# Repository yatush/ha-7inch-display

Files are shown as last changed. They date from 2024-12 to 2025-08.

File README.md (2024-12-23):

ha-7inch-display
================
**Wall mounted 7 inch touch display for HA, based on OrangePi Zero 3, with motion detector.**

# Background
A project to create a HA display to mount on walls. Featuring:
* 7 inch touch display.
* Fully functional unix working running on [OrangePi Zero 3](http://www.orangepi.org/html/hardWare/computerAndMicrocontrollers/details/Orange-Pi-Zero-3.html).
* Power supply and OrangePi fits into outlet box (deep version of it).
* Motion sensor to wake up on pre-defined distance movement.

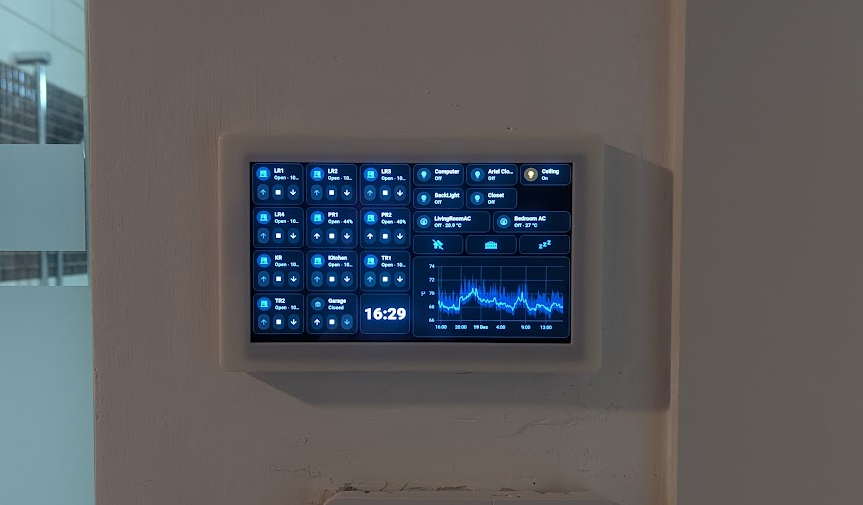
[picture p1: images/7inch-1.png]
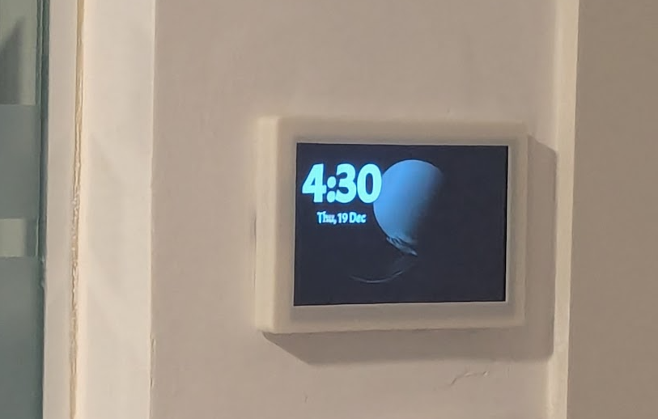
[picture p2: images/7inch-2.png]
 

# Hardware

## Touch screen - 7 Inch Touch Screen IPS 1024x600 HD LCD HDMI-compatible

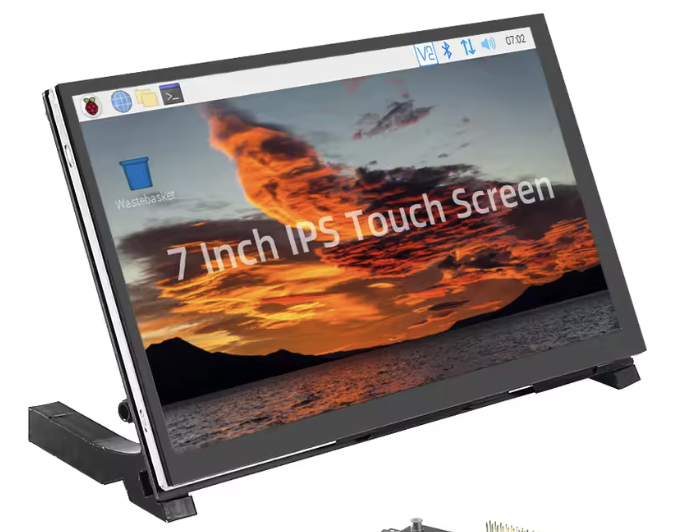
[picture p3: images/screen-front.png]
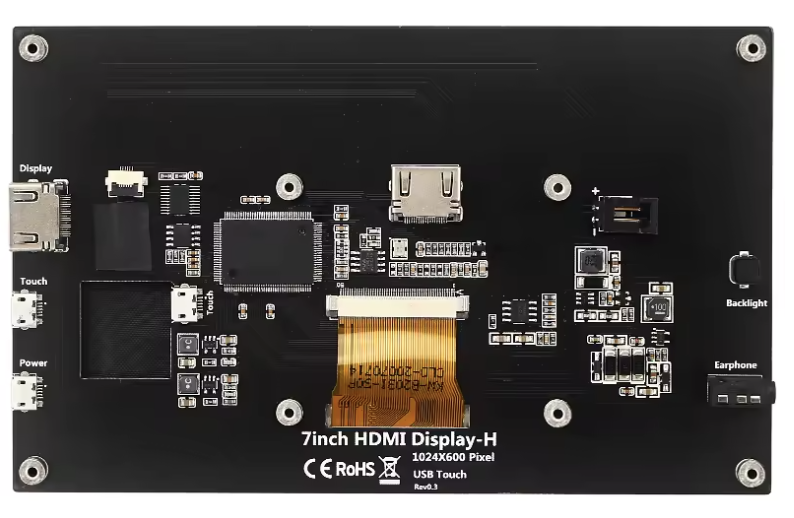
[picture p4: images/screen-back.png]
 

* 1024x600 IPS resolution
* [Aliexpress link](https://www.aliexpress.com/item/1005001485174459.html)
* Please make sure you choose the one with the back looking like this - HDMI connector and four round "legs" on the corners.
* Price: ~36 USD.

## Power supply - AC-DC to DC Step-Down Power Supply Module AC85-220V to DC 5V 2A



* 110V/220V -> 5V2A converter that fits in the wall box.
* [Aliexpress link](https://www.aliexpress.com/item/1005005142108650.html)
* Price: ~6 USD.

## SBC - Orange pi zero 3 (2GB Ram version)

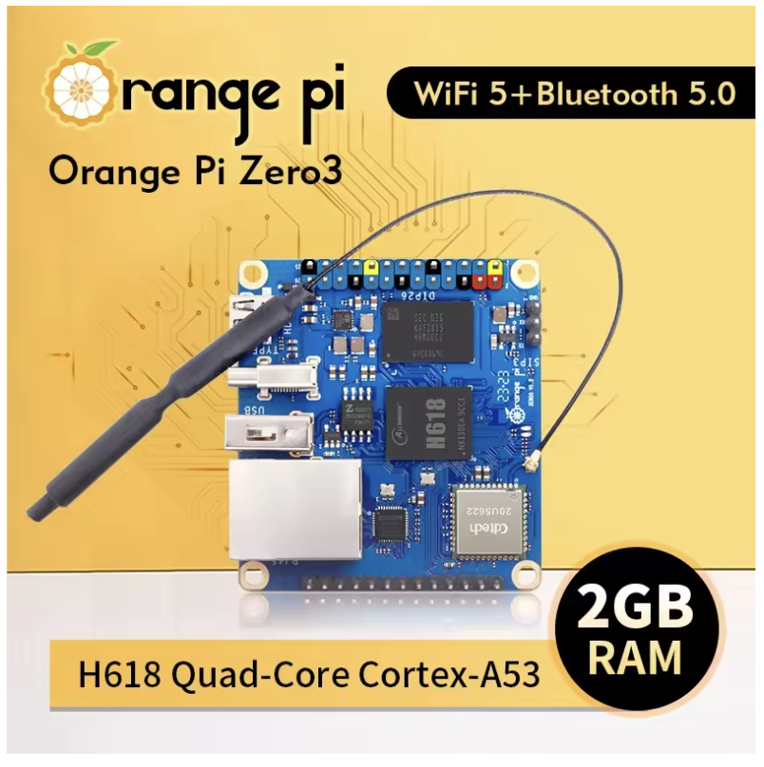
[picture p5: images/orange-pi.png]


* Small factor SBC
* I've tried running this with Raspberry pi 4 - it's both more expensive, heats up more, and needs more power.  The Orange Pi Zero 3 is perfect for this usage.
* [Aliexpress link](https://www.aliexpress.com/item/1005006170910291.html)
* Price: ~26 USD.

## Passive cooling case for the Orange Pi

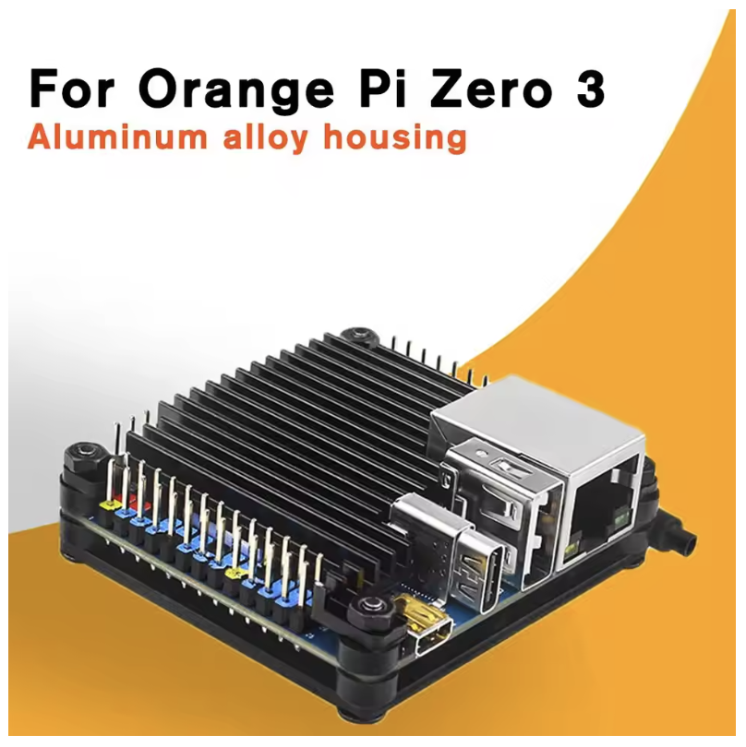
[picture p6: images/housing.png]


* Also protects from physical damage.
* [Aliexpress link](https://www.aliexpress.com/item/1005005886279442.html)
* Price: ~4 USD

## SD card for the SBC

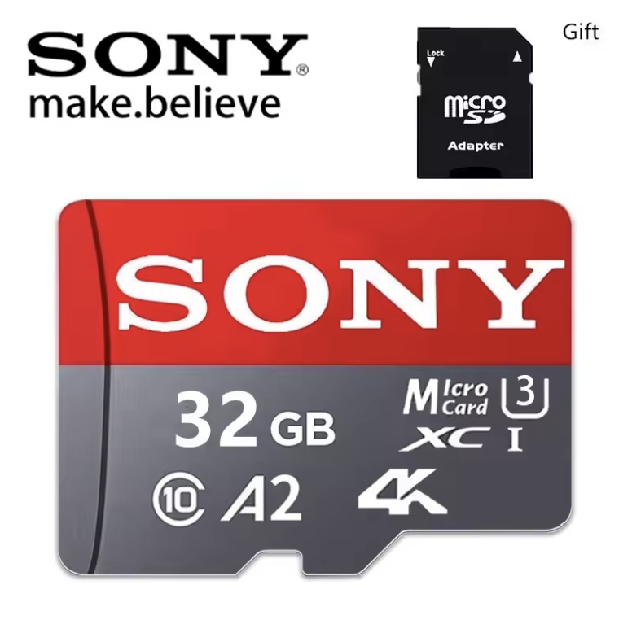
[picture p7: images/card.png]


* Any 32 GB micro SD card will do the work.
* [Aliexpress link](https://www.aliexpress.com/item/1005007897862434.html)
* An SDCard reader is also needed, to burn the image to the SD Card.
* Price: ~3 USD.

## HDMI cable to connect the Orange Pi to the screen

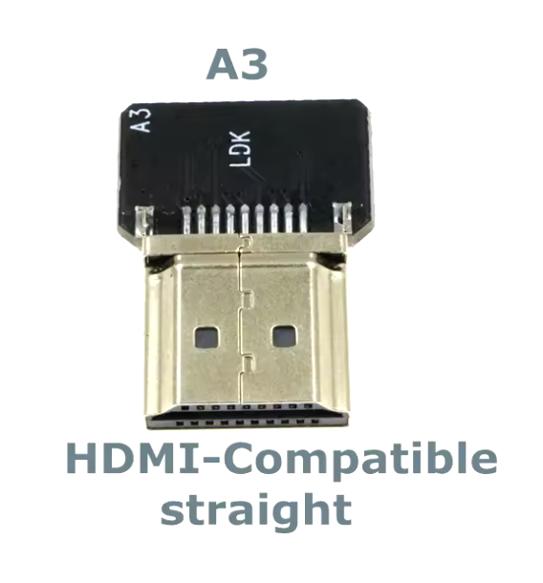
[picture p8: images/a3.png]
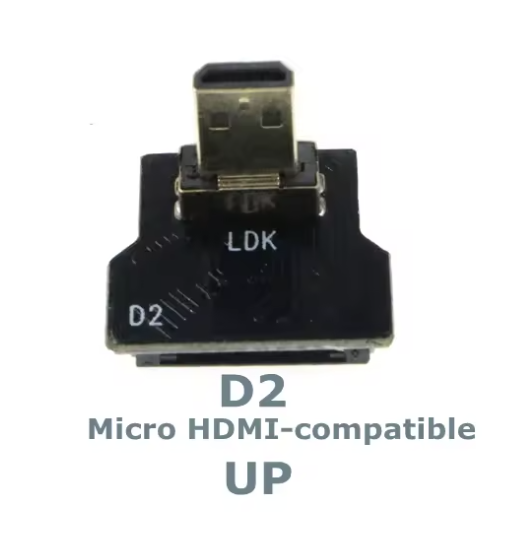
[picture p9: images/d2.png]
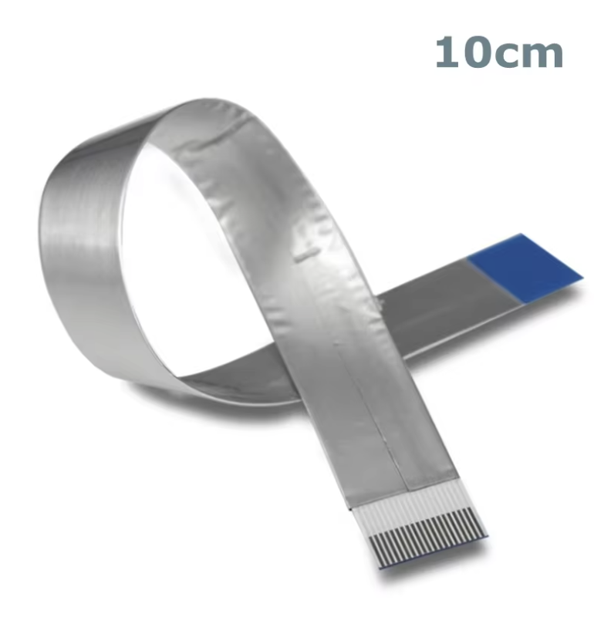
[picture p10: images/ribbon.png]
  

* Built out of three parts - two connectors and the ribbon:
  * The first connector - model A3.
  * The second connector - model D2.
  * the connecting ribbon - length of 10 c"m.
* [Aliexpress link](https://www.aliexpress.com/item/1005006426262787.html) (choose the three parts separately).
* Price: ~7 USD for all three parts.

## USB cable to connect the Orange Pi to the screen

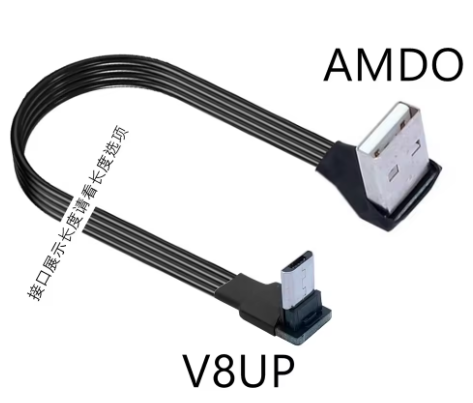
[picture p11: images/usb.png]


* Pay attention to the connectors (AMDO V8UP)
* Length of 10cm.
* [Aliexpress link](https://www.aliexpress.com/item/1005005979020420.html)
* Price: ~5 USD.

## USB-C Power plug

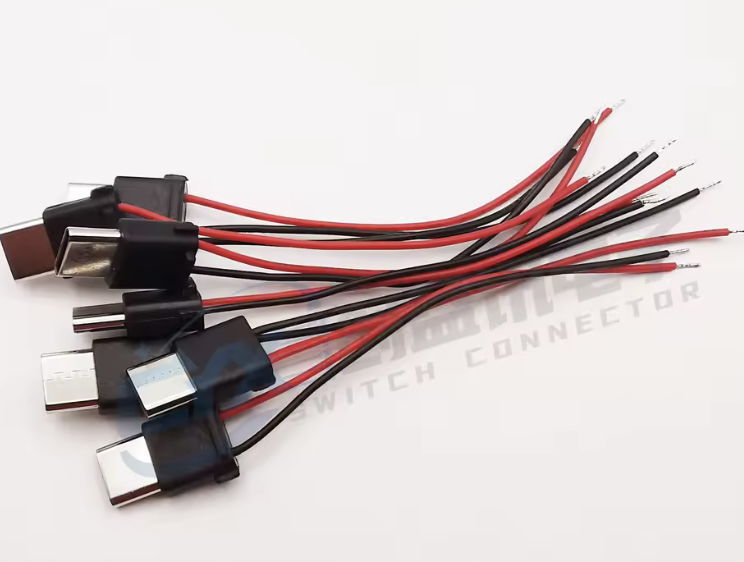
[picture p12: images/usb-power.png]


* Any other compact USB-C plug should do the work.
* [Aliexpress link](https://www.aliexpress.com/item/1005005419728912.html)
* Price: ~3 USD (for a pack of 10, only 1 is needed)

## Motion sensor - LD2410b

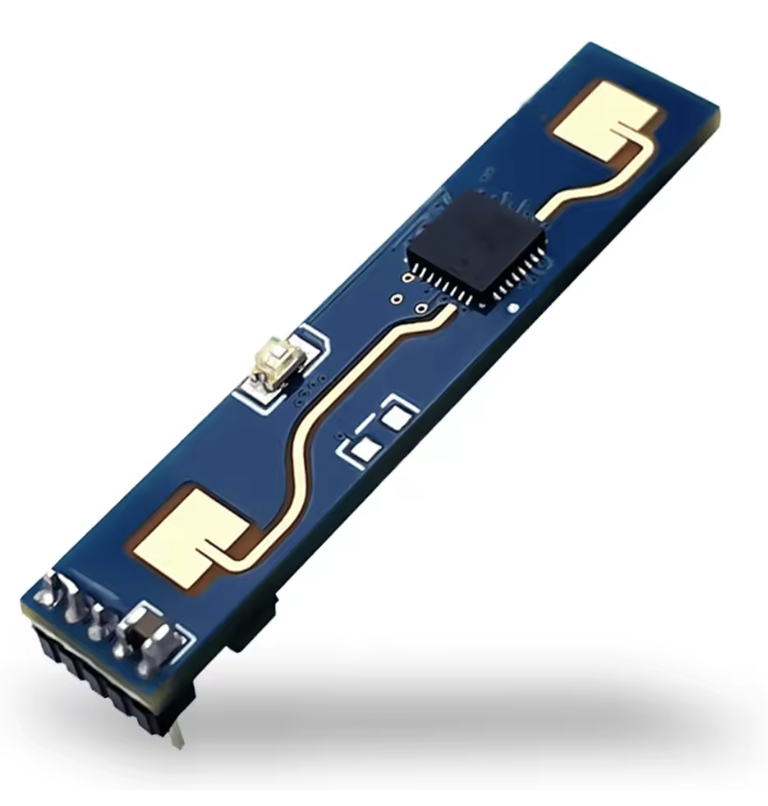
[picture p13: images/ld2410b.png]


* Choose a model where there are welded pins.
* [Aliexpress link](https://www.aliexpress.com/item/1005005242873516.html)
* Price: ~3 USD

## Motion sensor cable

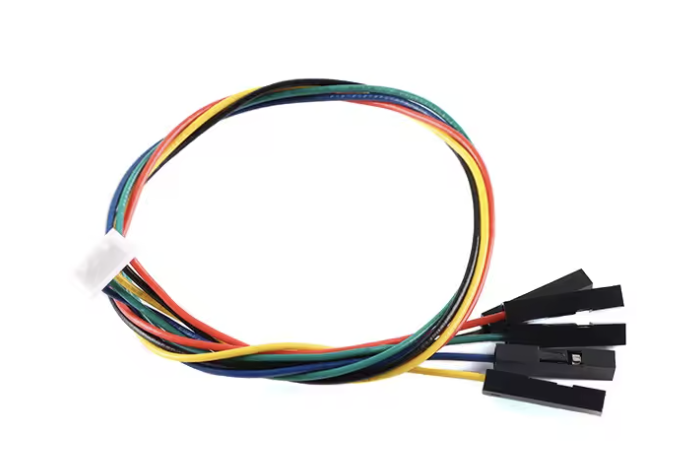
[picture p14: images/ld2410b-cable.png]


* [Aliexpress link](https://www.aliexpress.com/item/1005007055937689.html)
* Price: ~1 USD

## Outlet box

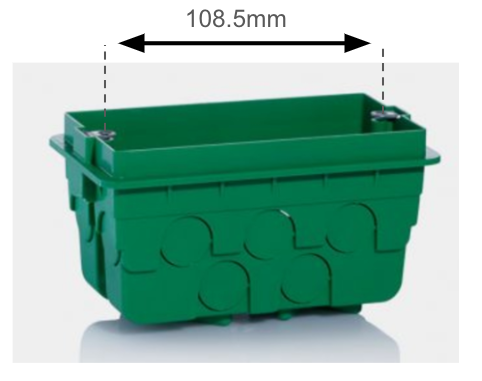
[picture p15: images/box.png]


* This is the outlet box I'm using.
* Important measurements:
  * Length: 121mm
  * Width: 67mm
  * Depth: 74mm
  * Distance between screws: 108.5mm
* For other between-screws-distance the 3d model should be modified, this should not be a problem.
* I think this is the minimum size for the outlet box, otherwise, all the electronics will not fit in.

## (Optional) Keyboard to control the display

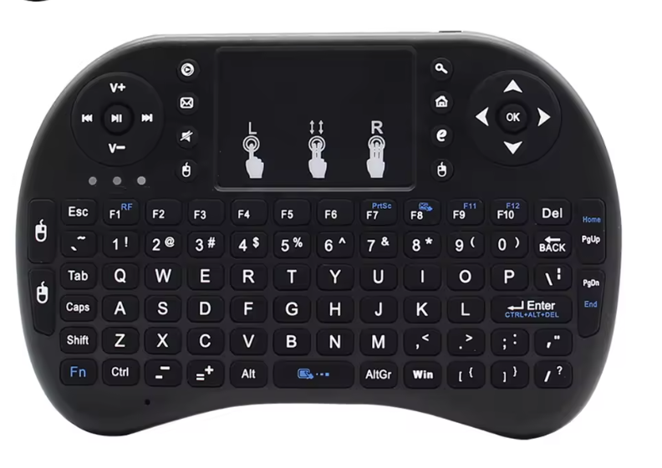
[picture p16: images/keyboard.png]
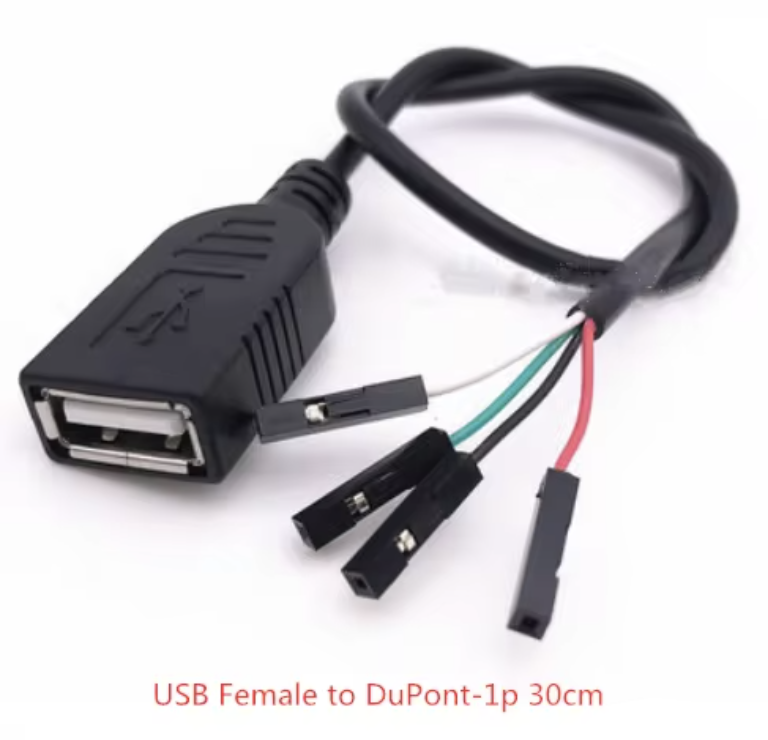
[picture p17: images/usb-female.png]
 

* There's no need while the system is "running" to control it via keyboard.
* However, for initial setup, and in case things go wrong for some reason, this is really convenient.
* Because OPI03 has only one usb pory (used for the screen), we need to also add a pin-connected USB port.
* [Aliexpress link - keyboard](https://www.aliexpress.com/item/1005004085232177.html)
* [Aliexpress link - USB port](https://www.aliexpress.com/item/1005004492194988.html)
* Price: ~4 USD + ~3 USD = ~7 USD.

# On the wall wiring diagram

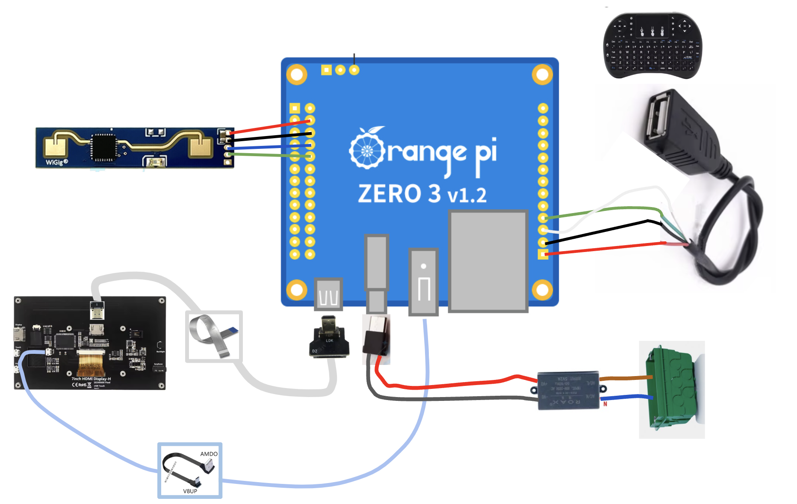
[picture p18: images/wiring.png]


* ***IMPORTANT:*** There's a power input connector in the back of the screen, it has to be removed - just pull the black plastic.

# Installation process

## Download and burn the Orange Pi OS(Arch) to the micro SD card
* Download the Debian Bookworm desktop image from [this](http://www.orangepi.org/html/hardWare/computerAndMicrocontrollers/service-and-support/Orange-Pi-Zero-3.html) site.
* Burn it to an micro SD card, following the instructions [here](http://www.orangepi.org/orangepiwiki/index.php/Orange_Pi_Zero_3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).

## Initial startup
* Connect according to the wiring diagram
* Once the linux image is up, connect to the internet (using the icon on the top left part of the screen).

## Add scripts content
* Add the content of /scripts/kiosk.sh to ```/home/orangepi/kiosk.sh```
* Add the content of /scripts/ld2410.py to ```/home/orangepi/ld2410.py```
* Change the variable values defined in the top part of ```kiosk.sh```.
* Make sure the two files are executable:
```
chmod 777 /home/orangepi/kiosk.sh
chmod 777 /home/orangepi/ld2410.py
```

## Install required components
Run all the following:
```
sudo apt-get install pip
```
```
sudo pip3 install keyboard --break-system-packages
```
```
sudo pip3 install git+https://github.com/vjsyong/LD2410.git --break-system-packages
```
```
sudo pip3 install requests --break-system-packages
```
```
sudo pip3 install pySerial --break-system-packages
```
```
sudo apt-get install unclutter-xfixes
```

## Set ```kiosk.sh``` to start on startup
* From the top right menu: Applications->Settings->Session and Startup -> Application and Autostart -> add ```/home/orangepi/kiosk.sh```

## Set timezone:
* See available timezones by:
```
timedatectl list-timezones
```
* Choose the right one and set it to the system by:
```
timedatectl set-timezone XXXX
```

## Remove sudo passwords for orangepi user
* Open a Terminal window and type:
```
sudo visudo
```
* In the bottom of the file, change to the following line:
```
orangepi ALL=(ALL) NOPASSWD: ALL
```

## Enable the UART5 for radar
* From the terminal, run
```
sudo orangepi-config
```
* System -> Hardware
* Go down to ```ph-uart5``` press space to toggle
* Save -> Back -> Reboot.

**After following the above process, the system should restart and HA should start**

# Changes to HA
## WallPanel
* I'm using the (WallPanel)[https://github.com/j-a-n/lovelace-wallpanel] for "screensaver" options. The python scripts omits "alt" every time it senses a movement in less than 150c"m from it, which triggers the wall panel to get out of the screensaver.
* The WallPanel configuration I'm using (for reference):
```
wallpanel:
  cards:
    - type: custom:digital-clock
      firstLineFormat: h:mm
      card_mod:
        style: |
          ha-card {
            background-color: transparent;
            box-shadow: none;
            border: none;
            font-size: 5vw;
            color: #aaa;
            font-family: 'Acme', sans-serif;
            display: inline-block;
          }
          ha-card .first-line {
            font-size: 20vw;
          }
          ha-card .second-line {
            font-size: 5vw;
          }
  enabled: false
  debug: false
  hide_toolbar: true
  hide_sidebar: true
  fullscreen: false
  idle_time: 15
  image_url: /
  image_animation_ken_burns: false
  image_order: random
  show_images: true
  show_progress_bar: false
  display_time: 120
  keep_screen_on_time: 0
  black_screen_after_time: 0
  control_reactivation_time: 1
  screensaver_entity: input_boolean.wallpanel_screensaver
  info_animation_duration_x: 300
  info_animation_duration_y: 180
  info_animation_timing_function_x: steps(10, end)
  info_animation_timing_function_y: steps(6, end)
  info_move_pattern: random
  info_move_interval: 0
  info_move_fade_duration: 2
  card_interaction: false
  style:
    wallpanel-screensaver-image-overlay:
      background: rgba(0,0,0,0.6)
    wallpanel-screensaver-info-box-content:
      background: '#00000000'
    wallpanel-screensaver-info-box:
      '--wp-card-width': 45vw
```
* The step function in ```info_animation_timing_function_x/y``` is used to reduce the CPU usage.
* I use dark images (so that while the screen is in screensaver mode, it doesn't emit a lot of light). A sample of backgrounds are available under the ```backgrounds``` directory.
* Once this is all done, in the URL of starting the HA (in the ```kiosk.sh``` script), add:

  https://HA_URL/DASHBOARD/0<b>?wp_enabled=true</b>

  to start the WallPanel on startup.

## Other HA changes
* I'm using the dark mode of HA - IMO makes it look much better.

# Things I've tried along the way
* The Orange Pi Zero 4 was chosen over Raspberry Pi 4 - It consumes less power, gets to lower temperature and is smaller (dimensions). Performance-wise, it's weaker, but good enough to run browser smoothly with the right tweaks.
* Temperature-wise - I've run this for over a month, and it runs ~70ºC. I never saw it goes above 77ºC.
* The specified monitor is a good balance between price and performace. Higher resolution monitors require more CPU resources, which means higher temperature and more power consumption.

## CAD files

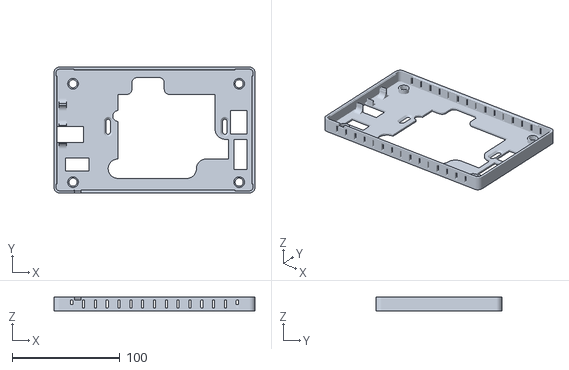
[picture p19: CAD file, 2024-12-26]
3d-print/base.stl
186.9 x 117.0 x 13.1

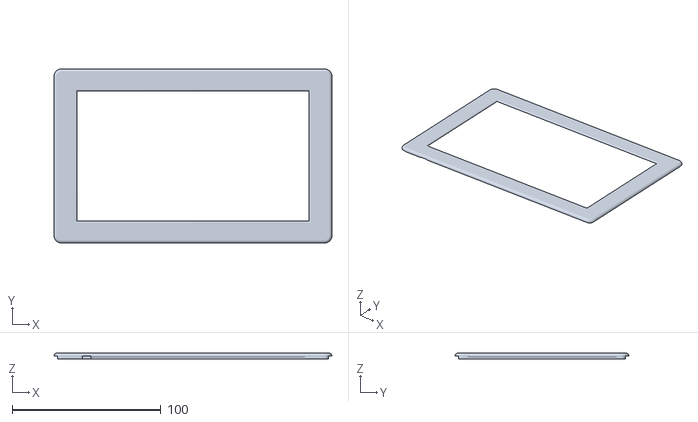
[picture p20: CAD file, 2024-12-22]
3d-print/top.stl
186.9 x 117.0 x 4.00

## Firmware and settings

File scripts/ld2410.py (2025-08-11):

from LD2410 import *
from requests import post
from datetime import datetime
import logging
import time
import keyboard
import threading
import subprocess
import sys
import getopt

print(str(sys.argv))

sensor = sys.argv[1]
url = sys.argv[2] + "api/states/" + sensor
headers = {"Authorization": "Bearer " + sys.argv[3]}
wakeup_dist = int(sys.argv[4])

def request_task(url, data, headers):
  post(url, json=data, headers=headers)

def fire_and_forget(url, data, headers):
  threading.Thread(target=request_task, args=(url, data, headers)).start()

def add_line_to_file(filename, line):
  """Adds a line to the end of a file.

  Args:
    filename: The name of the file to add the line to.
    line: The line to add to the file.
  """
  try:
    with open(filename, 'a') as f:
      f.write(line + '\n')
  except FileNotFoundError:
    print(f"Error: File '{filename}' not found.")
  except Exception as e:
    print(f"An error occurred: {e}")

def is_wifi_connected():
  """
  Checks if the computer is connected to a wifi network.

  Returns:
    True if connected, False otherwise.
  """
  try:
    # Use nmcli to get the wifi connection status
    output = subprocess.check_output(['nmcli', '-t', '-f', 'STATE', 'general']).decode('utf-8')
    return output == "connected"
  except subprocess.CalledProcessError:
    # If nmcli command fails, assume no connection
    return False

def reboot():
  """Reboots the system."""
  try:
    subprocess.run(['sudo', 'reboot'])
  except subprocess.CalledProcessError as e:
    print(f"Error rebooting: {e}")

def main():
  radar=LD2410("/dev/ttyS5", PARAM_BAUD_256000, verbosity=logging.INFO)
  fw_ver = radar.read_firmware_version()
  print(fw_ver)
  radar.edit_detection_params(8, 8, 1)
  radar.edit_gate_sensitivity(3, 50, 40)
  detection_params = radar.read_detection_params()
  print(detection_params)

  radar.start()

  last_movement = False
  last_distance = 1000
  last_time = datetime.now()
  move_10 = False
  dist_10 = 10000
  first_unconnected_time = datetime.now()
  had_wifi = is_wifi_connected()
  reboot_period = 300 if had_wifi else 3600
  add_line_to_file('reboots.log', 'Start time: ' + datetime.now().strftime("%Y-%m-%d %H:%M:%S"))

  while True:
    data = radar.get_data();
    movement = data[0][0] % 2 == 1
    distance = data[0][1]
    now = datetime.now()
    move_10 = move_10 or movement
    dist_10 = min(dist_10, distance)

    if (now - last_time).total_seconds() > 10:
      if not is_wifi_connected():
        if had_wifi:
          had_wifi = False
          first_unconnected_time = datetime.now()
          add_line_to_file('reboots.log', 'Lost wifi:' + datetime.now().strftime("%Y-%m-%d %H:%M:%S"))
        elif (now - first_unconnected_time).total_seconds() > reboot_period:
          add_line_to_file('reboots.log', 'Reboot no wifi:' + datetime.now().strftime("%Y-%m-%d %H:%M:%S"))
          reboot()
      else:
        if not had_wifi:
          add_line_to_file('reboots.log', 'Gained wifi:' + datetime.now().strftime("%Y-%m-%d %H:%M:%S"))
        had_wifi = True
        reboot_period = 300

      temp = 0
      try:
        temp = int(int(subprocess.check_output(['cat', '/sys/class/thermal/thermal_zone0/temp']))/100)/10
      except Exception as e:
        temp = -1
      fire_and_forget(url + "_distance", headers=headers, data= {
        "state": dist_10 if move_10 else "unknown",
        "attributes": {
          "unit_of_measurement": "cm",
          "device_class": "distance",
          "state_class": "measurement"
        }
      })
      fire_and_forget(url + "_movement", headers=headers, data= {
         "state": "on" if move_10 else "off",
         "attributes": {
           "device_class": "motion"
         }
      })
      fire_and_forget(url + "_temp", headers=headers, data= {
        "state": temp,
        "attributes": {
          "unit_of_measurement": "°C",
          "device_class": "temperature",
          "state_class": "measurement"
        }
      })
      last_time = now
      move_10 = False
      dist_10 = 10000
      radar.ser.reset_input_buffer()
    if movement and distance < wakeup_dist:
      keyboard.send('alt')
    time.sleep(0.25)
  radar.stop()

if __name__ == "__main__":
  main()

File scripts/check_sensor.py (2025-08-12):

import sys
import time
import serial.tools.list_ports
from LD2410 import LD2410, PARAM_BAUD_256000

def find_ld2410_port():
    """Scans serial ports and returns the device path for an LD2410 sensor."""
    ports = serial.tools.list_ports.comports()
    if not ports:
        print("❌ No serial ports found on this system.")
        return None

    print("🔎 Searching for LD2410 sensor...")
    for port in ports:
        try:
            radar = LD2410(port.device, PARAM_BAUD_256000, verbosity=0)
            if radar.read_firmware_version():
                print(f"✅ Found LD2410 at: {port.device}")
                radar.stop()
                return port.device
        except Exception:
            continue
    print("❌ LD2410 sensor not found.")
    return None

def monitor_radar():
    """Finds the radar and prints its live data until stopped."""
    port = find_ld2410_port()
    if not port:
        sys.exit(1)

    radar = None
    try:
        radar = LD2410(port, PARAM_BAUD_256000, verbosity=0)
        
        # Using some basic default parameters for good performance
        radar.edit_detection_params(max_gate=8, max_moving_gate=8, max_static_gate=1)
        
        radar.start()
        print("\n--- Starting Live Radar Monitoring ---")
        print("Press Ctrl+C to stop.")

        while True:
            data = radar.get_data()
            
            # The get_data() method returns data only when a target is detected
            if data:
                # data[0][0] indicates the target type: 1 for moving, 2 for static
                is_moving = (data[0][0] == 1)
                distance = data[0][1]

                status_str = "Yes" if is_moving else "No "
                distance_str = f"{distance} cm"
            else:
                # No target detected within the configured gates
                status_str = "No "
                distance_str = "N/A"

            # The '\r' character moves the cursor to the beginning of the line,
            # allowing us to overwrite it for a "live" display.
            # Extra spaces at the end clear any previous, longer line.
            print(f"Movement Detected: {status_str} | Distance: {distance_str}      ", end='\r')
            sys.stdout.flush()
            
            time.sleep(1)

    except KeyboardInterrupt:
        print("\n--- Stopping Radar ---")
    finally:
        if radar:
            radar.stop()
        print("Monitoring stopped.")

if __name__ == "__main__":
    monitor_radar()
